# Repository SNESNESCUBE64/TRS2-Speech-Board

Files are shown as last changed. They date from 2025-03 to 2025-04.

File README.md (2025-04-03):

# TRS2-Speech-Board
This is a mod for adding speech to TRS2 Arcade PCBs. These do not natively support speech like the TRS1 PCB sets which utilized a M58817 speech IC. The TRS2 speech board utilizes a Raspberry Pi Pico 2 equipped with CircuitPython to play speech samples from one of four pre-programmed speech sets.

[Demo Video](https://www.youtube.com/watch?v=-4g9nGpEcIQ)

## Installation Instructions
Proper written installation instructions coming soon.

[Video Tutorial](https://youtu.be/8o_55nDMGbg?si=-cQZ4i4qdC0Jirtd)

## Controls and Adjustments
There are two buttons, volume adjustment, and a set of 8 dip switches. 

The "Test" button brings the speech module into a self test mode in which it plays all the speech clips in the set. You can exit the speech test early by pressing the test button again. If hooked up to a python terminal, it also print out information about the state of the dip switches and databus. If the expansion dip switch is enabled it will enter in an expansion lamp test mode. To exit that test mode, press the test button again. The "Reset" button does exactly as it says. When pressed, it resets the module to the start of the program. The volume can be adjusted by turning the knob labeled "voice volume". 

The dip switch options can be used to change how certain aspects of the speech board behaves. *For stock operation: all dip switch settings should be set to "off"*. The muted option puts the board in a state in which it will not play any audio. The speech set setting changes with set of samples plays. Set 0 is the original set. Start up sound plays a clip when the module is activated on bootup. Engine Trouble Delay is just how much time passes between each time the "Engine Trouble" voice line is played. If desired the "Engine Trouble" line can be disabled. The last option is the Expansion enable. Because there were extra pins available, code was written to support a lamp display that is based on game conditions. Turning it on 

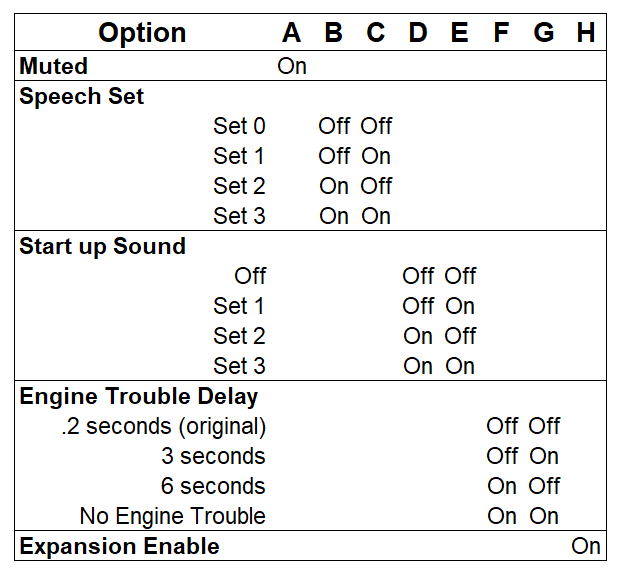
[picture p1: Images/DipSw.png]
Dip switch options


## Theory of Operation
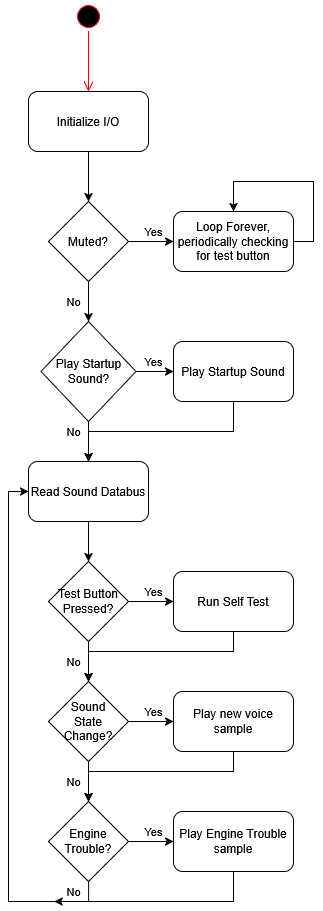
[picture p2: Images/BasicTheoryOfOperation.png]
Theory of operation

## Speech Board Hardware

### Bill of Materials
|  **Reference** | **Value** | **Part Number** |
|:---|:---|:---|
| C1,C3 | 100uF | 25YXM100MEFR6.3X11 |
| C2, C4-C9, C12 | 100nF | FG28X7R1H104KNT00 |
| C10 | 100nF (Poly) | R82DC3100DQ50J |
| C11 | 10nF (Poly) | R82EC2100Z350K |
| P1 | 12 pin connector | LHA-12-TRB |
| P2 | 10 pin connector | LHA-10-TRB |
| R1,R2 | 330 | Generic 1/4W 6.3mm Resistor |
| R3 | 50k | Generic 1/4W 6.3mm Resistor |
| R4-R6 | 100k | Generic 1/4W 6.3mm Resistor |
| R7 | 6.8k | Generic 1/4W 6.3mm Resistor |
| R8 | 3.9k | Generic 1/4W 6.3mm Resistor |
| R9 | 47 | Generic 1/4W 6.3mm Resistor |
| RN1 | 4.7k x 10 | 4611X-101-472LF |
| RN2 | 100k x 4 | 4605X-101-104LF |
| SW1 | DIPSW x 8 | Generic 8 switch dip switch |
| SW2, SW3 | Push Button | Generic Tactile Push Button |
| U1 | Pico 2 | Raspberry Pi Pico 2 |
| U2 | 74HCT374 | SN74HCT374N or 74LS374N |
| U3 | TL032 | TL032CP |
| U4,U5 | TXS0108 | TXS0108EPW |
| VR1 | 1k | Pot:PT10MV10-102A2020-S Knob:5116 |
### Schematics
Schematics

### Render (to be replaced with final PCB design images)
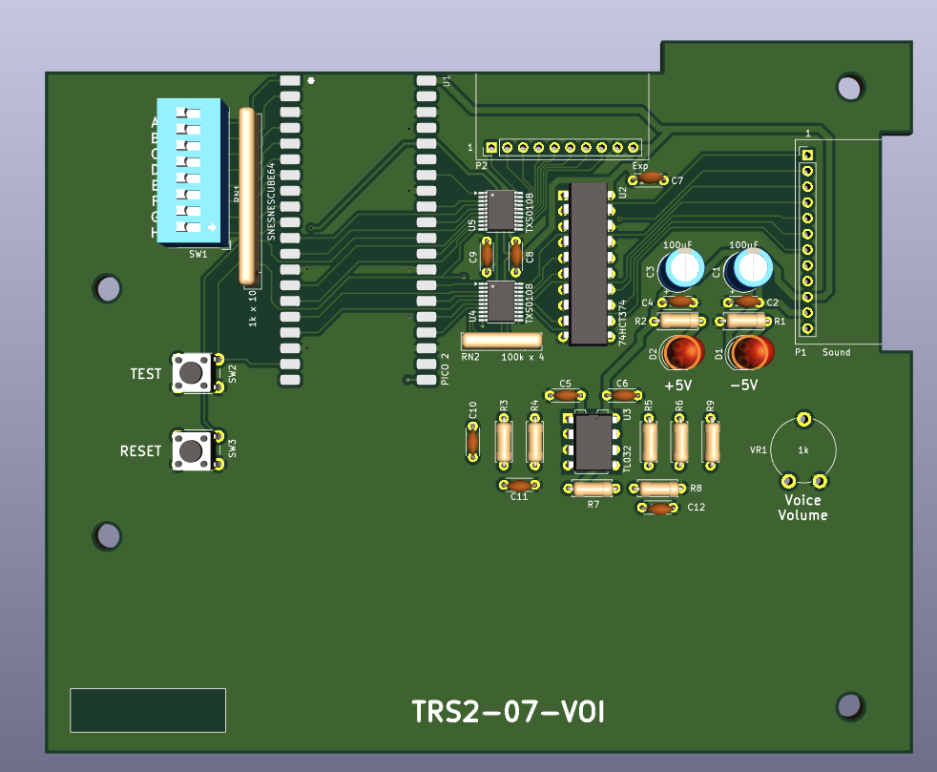
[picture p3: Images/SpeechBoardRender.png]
PCB Render


## Speech Board Tester Hardware
This is just a Jamma adapter that was used to provide an easy hookup to a test bench for power and the speaker. It was used for testing the speech board when the algorithm was still being developed. It serves no real purpose now that the code has been developed but is being provided anyway. 

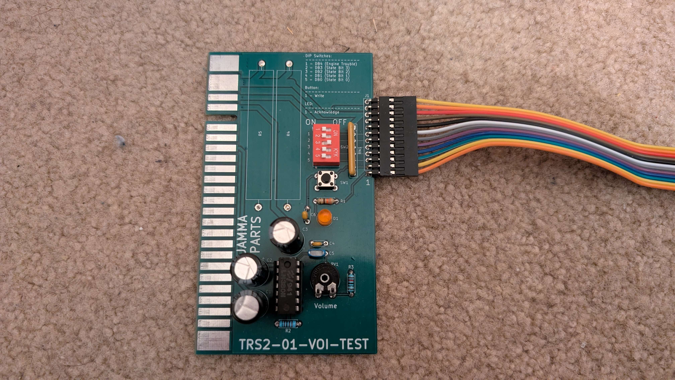
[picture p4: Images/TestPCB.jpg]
Test PCB


## Sound Board ROM Patches
Two ways have been provided for patching the original TRS2 sound ROM: A hardware patch and a software patch. The original TRS2 sound ROM would not communicate correctly with the new speech board. As such a patch would have been required to write to the speech module. 

### Hardware Patch
The hardware patch is a simple board in which the original sound rom is plugged into a daughterboard which is then plugged into the original ROM socket. It works by switching which chip outputs code at certain addresses. Essentially making it a hardware patch.

1. Program the GAL22V10 with the "TRS2-Patch-Romless.jed" file
2. Assemble (if not done so) the PCB like in the image below
3. Insert it into the 3I socket on the ROM board, minding the pin 1 markets

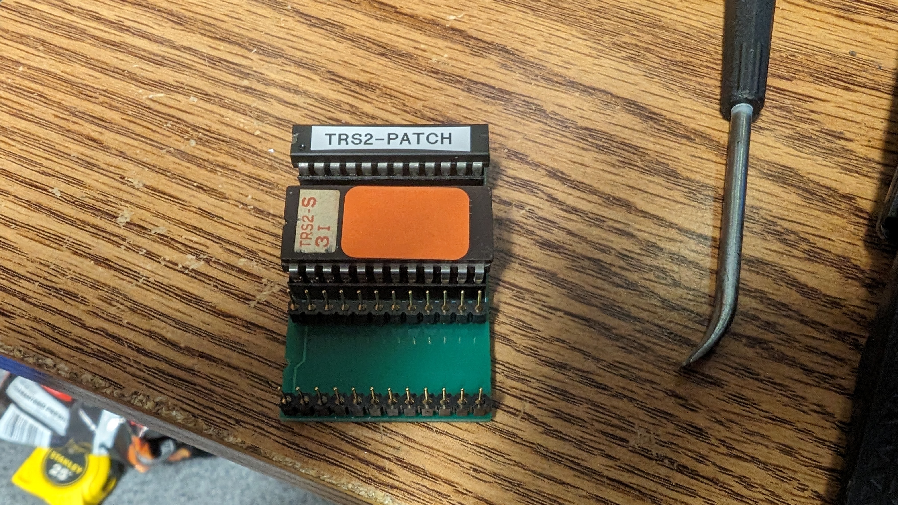
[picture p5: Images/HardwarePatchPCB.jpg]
Hardware Patch PCB

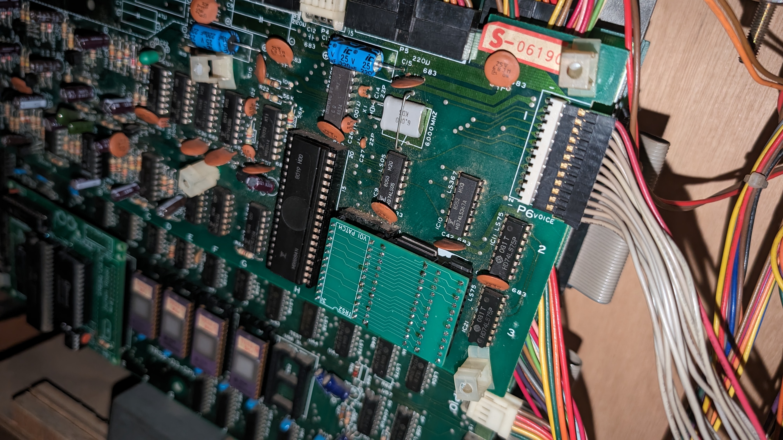
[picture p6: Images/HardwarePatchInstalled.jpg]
Hardware Patch PCB Installed


### Software Patch
In case that one doesn't want to use the daughterboard, a new single rail 2716 EPROM can be burned using a patched ROM file that replaces the original at 3I.

1. Dump the sound ROM located at 3I 
2. Patch the sound ROM with the trs2s3i_SWPatch.ips patch file using LunarIps
3. Verify that the sound ROM checksum is now *D068ED11*
4. Burn the new ROM onto a 2716 EPROM
5. Replace the sound ROM located at 3I with the patched ROM

### Patch Source Code 
This code was written in 8035 assembly. The memory address 0x20 (unused in the game) now stores the speech bus state.

```Asm
Address Instruction Opcode
--------------------------------
104     CALL $2A0   54 A0

2A0     ANL a,#$0F  53 0F
2A2     MOV r0,a    A8
2A3     IN a,p2     0A
2A4     ANL a,#$20  53 20
2A6     RR a        77
2A7     ORL a,r0    48
2A8     OUTL bus,a  02
2A9     ANL a,#$20  53 0F
2AB     MOV r0,#20  B8 20
2AD     RET         83

2B0     MOV r7,#$60 BF 60
2B2     MOVX a,@r0  80
2B3     CPL a       37
2B4     ORL a,#$10  43 10
2B6     OUTL bus,a  02
2B7     RET         83

614     CALL $2B0   54 B0
```

## Special Thanks
A very special thanks goes out to Markus Karrer Ostermayer of the awesome site [The Radar Scope Pages](https://www.ostermayer.ch/index.html). He had performed the initial research that I based this project off of as well as providing samples of the original speech. Without his contributions, this project would have not been possible.

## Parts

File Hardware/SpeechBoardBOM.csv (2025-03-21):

Reference | Value | Datasheet | Footprint | Qty | DNP
C1,C3 | 100 | ~ | Capacitor_THT:CP_Radial_D6.3mm_P2.50mm | 2
C2,C4,C5,C6,C7,C8,C9,C12 | 100nF | ~ | Capacitor_THT:C_Disc_D4.3mm_W1.9mm_P5.00mm | 8
C10 | 100nF (P) | ~ | Capacitor_THT:C_Disc_D4.3mm_W1.9mm_P5.00mm | 1
C11 | 10nF (P) | ~ | Capacitor_THT:C_Disc_D4.3mm_W1.9mm_P5.00mm | 1
D1,D2 | LED | ~ | LED_THT:LED_D5.0mm | 2
P1 | Conn_01x12 | ~ | Connector_PinHeader_2.54mm:PinHeader_1x12_P2.54mm_Vertical | 1
P2 | Conn_01x05 | ~ | Connector_PinHeader_2.54mm:PinHeader_1x10_P2.54mm_Vertical | 1
R1,R2 | 330 | ~ | Resistor_THT:R_Axial_DIN0207_L6.3mm_D2.5mm_P7.62mm_Horizontal | 2
R3 | 51k | ~ | Resistor_THT:R_Axial_DIN0207_L6.3mm_D2.5mm_P7.62mm_Horizontal | 1
R4,R5,R6,RN2 | 100k | -- mixed values -- | -- mixed values -- | 4
R7 | 6.8k | ~ | Resistor_THT:R_Axial_DIN0207_L6.3mm_D2.5mm_P7.62mm_Horizontal | 1
R8 | 3.9k | ~ | Resistor_THT:R_Axial_DIN0207_L6.3mm_D2.5mm_P7.62mm_Horizontal | 1
R9 | 47 | ~ | Resistor_THT:R_Axial_DIN0207_L6.3mm_D2.5mm_P7.62mm_Horizontal | 1
RN1 | 4.7k | http://www.vishay.com/docs/31509/csc.pdf | Resistor_THT:R_Array_SIP11 | 1
SW1 | SW_DIP_x08 | ~ | Button_Switch_THT:SW_DIP_SPSTx08_Slide_9.78x22.5mm_W7.62mm_P2.54mm | 1
SW2 | Test Button | ~ | Button_Switch_THT:SW_PUSH_6mm | 1
SW3 | Reset Button | ~ | Button_Switch_THT:SW_PUSH_6mm | 1
U1 | Pico2 | https://datasheets.raspberrypi.com/pico/pico-2-datasheet.pdf | Custom Footprints:Pico2 | 1
U2 | 74HCT374 | http://www.ti.com/lit/gpn/sn74LS374 | Package_DIP:DIP-20_W7.62mm | 1
U3 | TL032 | http://www.ti.com/lit/ds/symlink/lm2904-n.pdf | Package_DIP:DIP-8_W7.62mm | 1
U4,U5 | TXS0108EPW | www.ti.com/lit/ds/symlink/txs0108e.pdf | Package_SO:TSSOP-20_4.4x6.5mm_P0.65mm | 2
VR1 | 1k | ~ | Potentiometer_THT:Potentiometer_Piher_PT-10-V10_Vertical | 1

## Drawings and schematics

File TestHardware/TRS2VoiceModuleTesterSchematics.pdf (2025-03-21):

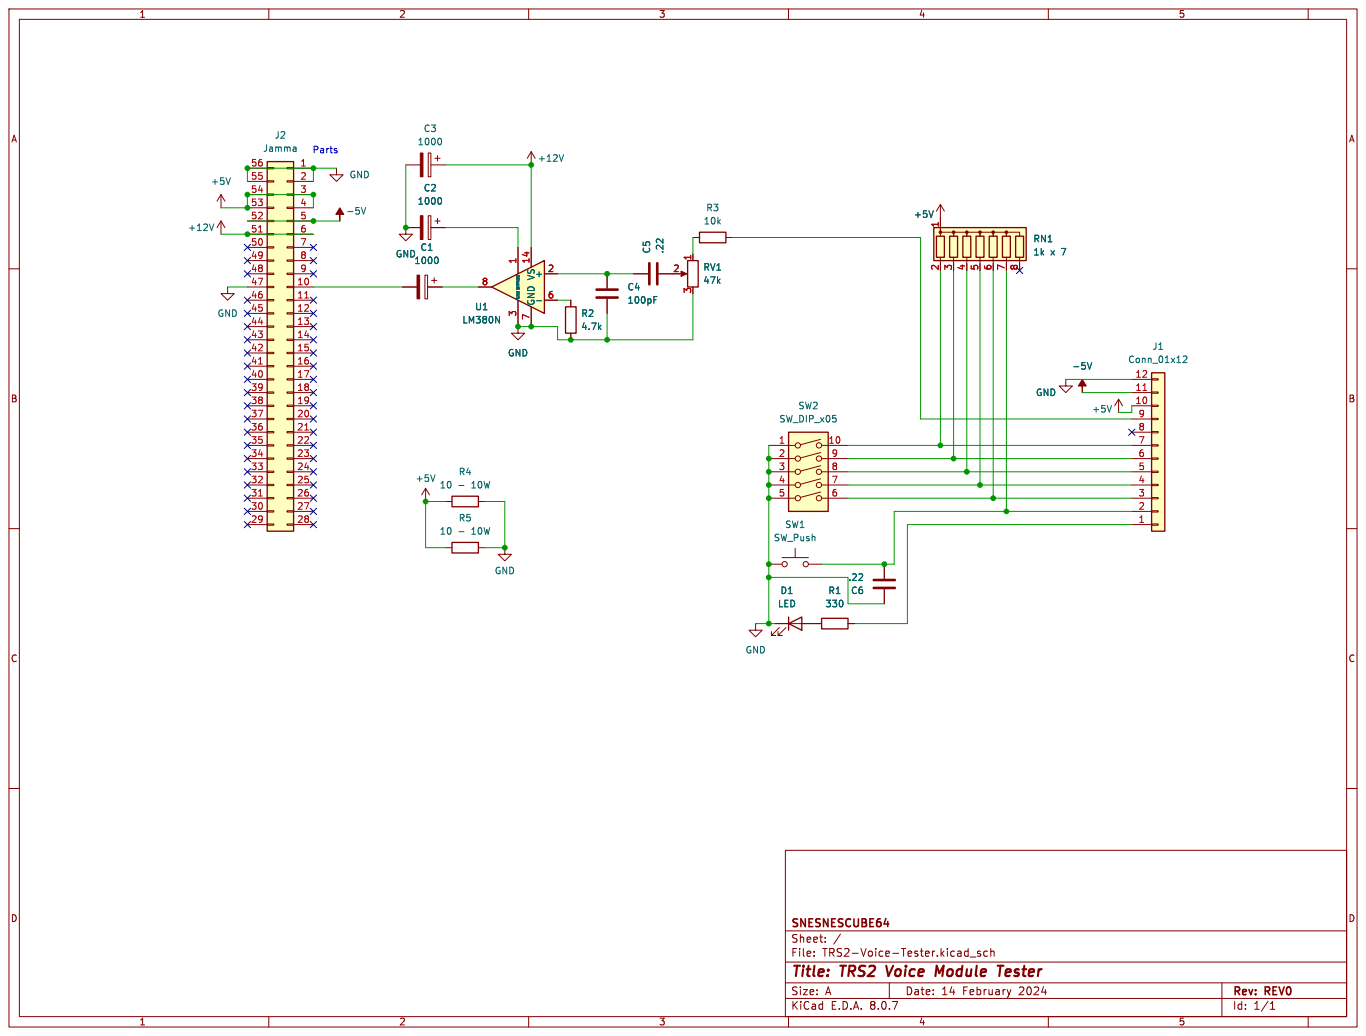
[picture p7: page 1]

Id: 1/1 Title: TRS2 Voice Module Tester File: TRS2-Voice-Tester.kicad_sch Sheet: / SNESNESCUBE64 R4

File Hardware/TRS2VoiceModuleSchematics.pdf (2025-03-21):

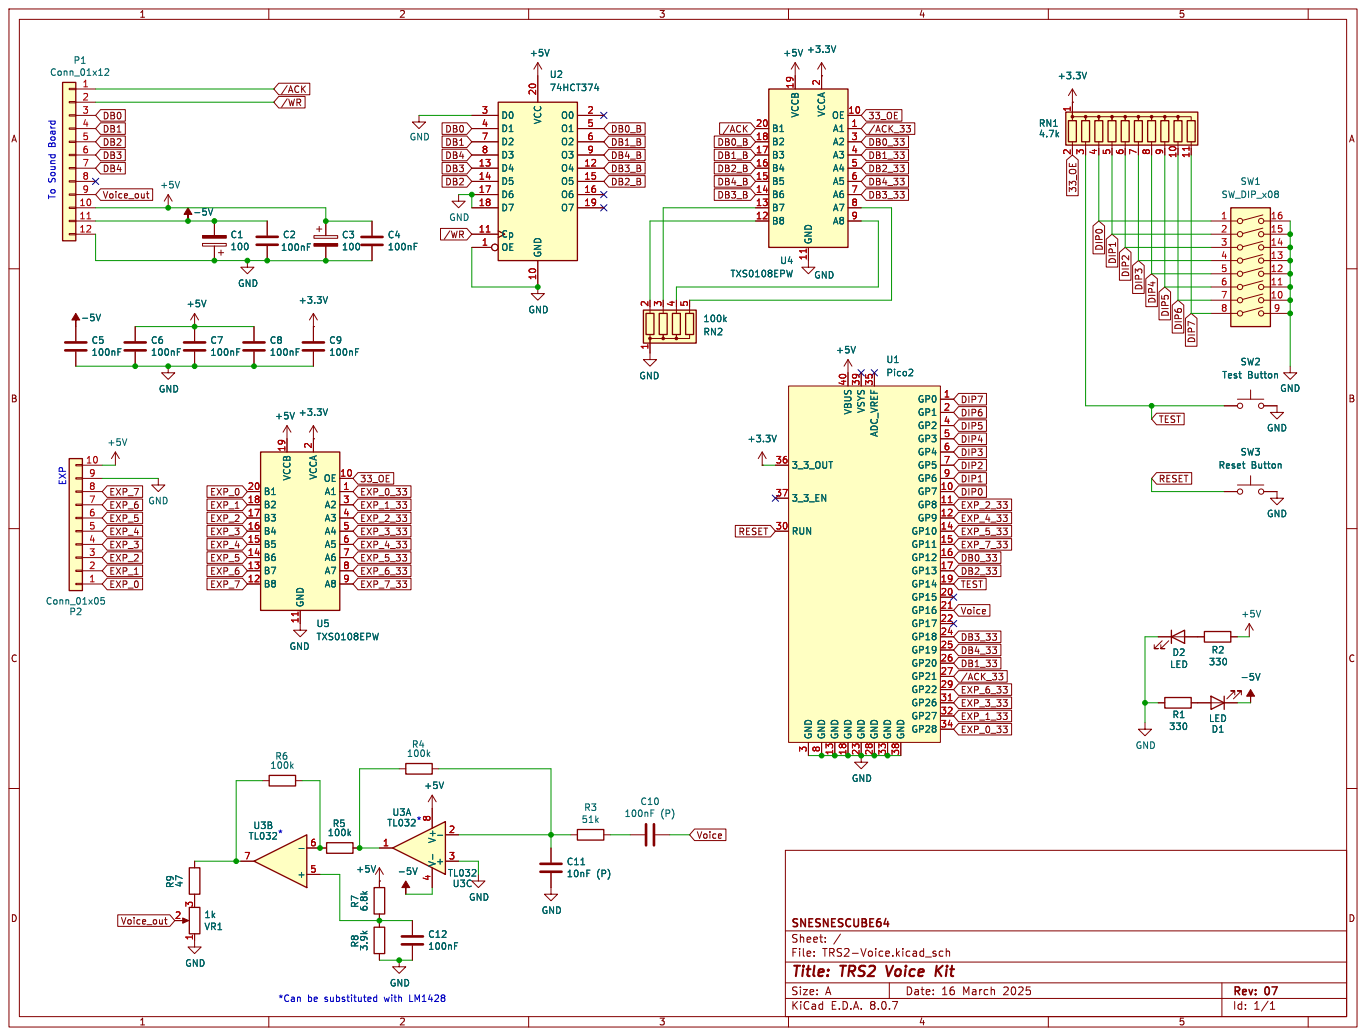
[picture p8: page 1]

Id: 1/1 Title: TRS2 Voice Kit File: TRS2-Voice.kicad_sch Sheet: / SNESNESCUBE64

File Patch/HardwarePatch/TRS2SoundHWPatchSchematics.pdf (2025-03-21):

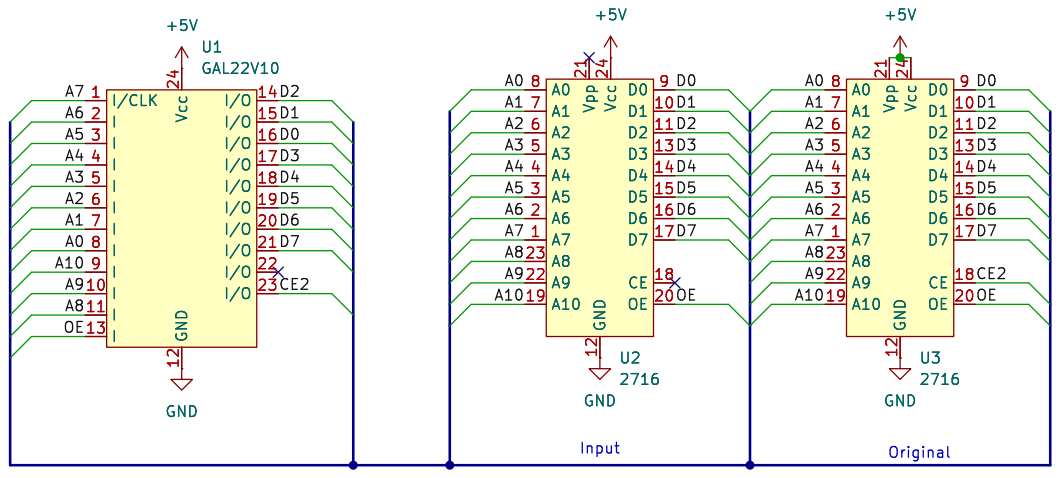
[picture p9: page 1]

Id: 1/1 Title: TRS2 Sound ROM Hardware Patch

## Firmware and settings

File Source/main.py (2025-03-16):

import board
import digitalio
import time
import audiomp3
import audiopwmio

import TRS2_VoiceConfig
import TRS2_VoiceDriver
import TRS2_TestMode
import TRS2_Exp

#Wait for the EZ20 amp to start up
time.sleep(1)

#Initialization
soundDatabus = TRS2_VoiceConfig.SoundDatabus()
soundDatabus.init()
voiceSettings = TRS2_VoiceConfig.VoiceSettings()
voiceSettings.init()
voiceDriver = TRS2_VoiceDriver.VoiceDriver()
led = digitalio.DigitalInOut(board.LED)
led.direction = digitalio.Direction.OUTPUT
led.value = False
testButton = digitalio.DigitalInOut(board.GP14)
testButton.direction = digitalio.Direction.INPUT

time.sleep(.1)
voiceSettings.readDipSwitches()
voiceDriver.voiceSet = voiceSettings.speechSet
voiceDriver.startupSet = voiceSettings.startupSound

exp = TRS2_Exp.ExpDriver()
exp.init(voiceSettings.expEnable)

soundDatabus.updateVoiceState()
lastVoiceState = soundDatabus.voiceState

#In case for some reason the user doesn't want the audio boad to play
while voiceSettings.muted:
    if not testButton.value:
        TRS2_TestMode.selfTest(soundDatabus, exp, voiceSettings, voiceDriver, testButton)
        while not testButton.value:
            pass

#Play the startup sound if 
if voiceSettings.startupSound > 0:
    led.value = True
    soundDatabus.ack.value = False
    voiceDriver.playStartup()
    while voiceDriver.voice.playing:
        pass
    led.value = False
    soundDatabus.ack.value = True
        
        
engineTroubleCounter = 0
engineTroubleMax = voiceSettings.engineTroubleDelay

#main loop
while True:
    soundDatabus.updateVoiceState()
    
    if not testButton.value:
        led.value = True
        soundDatabus.ack.value = False
        TRS2_TestMode.selfTest(soundDatabus, exp, voiceSettings, voiceDriver, testButton)
        led.value = False
        soundDatabus.ack.value = True
        while not testButton.value: #this should take priority
            pass
        time.sleep(.2)
        
    #check for a change in the state
    if lastVoiceState != soundDatabus.voiceState:
        time.sleep(.2)
        compState = soundDatabus.voiceState
        soundDatabus.updateVoiceState()
        #double check that it wasn't a blip
        if compState == soundDatabus.voiceState:          
            while voiceDriver.voice.playing:
                pass
            led.value = True
            soundDatabus.ack.value = False
            voiceDriver.playVoice(soundDatabus.voiceState)
            lastVoiceState = soundDatabus.voiceState
    
    #Check if there is an engine trouble status       
    if engineTroubleMax > 0:
        if soundDatabus.engineTroubleState and not voiceDriver.voice.playing and engineTroubleCounter == 0:
            time.sleep(.2)
            soundDatabus.updateVoiceState()
            #double check that it wasn't a blip
            if soundDatabus.engineTroubleState:          
                led.value = True
                soundDatabus.ack.value = False
                voiceDriver.playVoice(16)
                engineTroubleCounter += 1
        
        #If the engine trouble voice played, increment the delay counter
        if soundDatabus.engineTroubleState and not voiceDriver.voice.playing:
            engineTroubleCounter += 1
            time.sleep(.1)
        
        #If we reach the threshold, reset the counter so the line can be played
        if engineTroubleCounter > engineTroubleMax or not soundDatabus.engineTroubleState:
            engineTroubleCounter = 0     
    
    #Turn the LED off whenever the module is done speaking
    if not voiceDriver.voice.playing:
        led.value = False
        soundDatabus.ack.value = True
    
    #For expansion lamp driver
    if voiceSettings.expEnable:
        exp.processState(soundDatabus, voiceDriver.voice.playing)
        
print("Should never reach this point")

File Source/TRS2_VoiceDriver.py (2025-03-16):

import board
import digitalio
import time
import audiomp3
import audiopwmio

GAME_OVER = 0
GAME_START = 1
BEEP = 2 #Not used
WAVE_COMPLETE = 3
WAVE_1_CHARLIE = 4
WAVE_1_BRAVO = 5
WAVE_1_ALPHA = 6
WAVE_1_CAUTION = 7
WAVE_2_CHARLIE = 8
WAVE_2_BRAVO = 9
WAVE_2_ALPHA = 10
WAVE_2_CAUTION = 11
WAVE_3_CHARLIE = 12
WAVE_3_BRAVO = 13
WAVE_3_ALPHA = 14
WAVE_3_CAUTION = 15
ENGINE_TROUBLE = 16

SPEECH_SET = ["Trouble.mp3",
              "Charlie.mp3",
              "Bravo.mp3",
              "Alpha.mp3",
              "UseCaution.mp3",
              "Complete.mp3",
              "EngineTrouble.mp3"]

STARTUP_SET = ["SayItLowStartup.mp3",
               "SayItHighStartup.mp3",
               "BonziStartup.mp3"]

BASE_PATH = "SoundSamples/"
    
class VoiceDriver:   
    voice = audiopwmio.PWMAudioOut(board.GP16)
    voiceSet = 0
    startupSet = 0
    currentFile  = open((BASE_PATH + "Set" + str(voiceSet) + "/" + SPEECH_SET[0]), "rb")
    decoder = audiomp3.MP3Decoder(currentFile)
        
    def playVoice(self, voiceID):
        speechSampleID = processSpeechID(voiceID, self.voiceSet)
        if speechSampleID != -1:
            self.currentFile.close()
            self.currentFile = open((BASE_PATH + "Set" + str(self.voiceSet) + "/" + SPEECH_SET[speechSampleID]), "rb")
            self.decoder.file = self.currentFile
            self.voice.play(self.decoder)
            
    def playStartup(self):
        if self.startupSet != 0:
            self.currentFile.close()
            self.currentFile = open((BASE_PATH + "Startup/" + STARTUP_SET[self.startupSet-1]), "rb")
            self.decoder.file = self.currentFile
            self.voice.play(self.decoder) 

def processSpeechID(status, speechSet):
    sampleID = -1
    
    if(status == GAME_START):
        sampleID = 0
    elif(status == WAVE_1_CHARLIE or status == WAVE_2_CHARLIE or status == WAVE_3_CHARLIE):
        sampleID = 1
    elif(status == WAVE_1_BRAVO or status == WAVE_2_BRAVO or status == WAVE_3_BRAVO):
        sampleID = 2
    elif(status == WAVE_1_ALPHA or status == WAVE_2_ALPHA or status == WAVE_3_ALPHA):
        sampleID = 3
    elif(status == WAVE_1_CAUTION or status == WAVE_2_CAUTION  or status == WAVE_3_CAUTION):
        sampleID = 4
    elif(status == WAVE_COMPLETE):
        sampleID = 5
    elif(status == ENGINE_TROUBLE):
        sampleID = 6
    
    return sampleID

def setTalking(talking):
    pass
        

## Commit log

2025-03-21 Added Hardware and Software Patch Source Files
    [TRS2_SOU_PATCH-B_Cu.gbr, TRS2_SOU_PATCH-B_Mask.gbr, TRS2_SOU_PATCH-B_Paste.gbr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]
2025-03-21 Added SPeech Board Hardware
    [SpeechBoardBOM.csv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]
2025-03-21 Updated Schematic Image
2025-03-21 Added Tester Hardware
    [TRS2-Voice-Tester-B_Cu.gbr, TRS2-Voice-Tester-B_Mask.gbr, TRS2-Voice-Tester-B_Paste.gbr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]
2025-03-21 Added PCB Render
